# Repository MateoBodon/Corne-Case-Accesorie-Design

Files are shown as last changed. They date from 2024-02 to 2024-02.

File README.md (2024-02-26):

# Magnetic Cases for the Typeractive Corne


## Introduction

Welcome to the repository hosting my magnetic keyboard case designs for the Typeractive Corne keyboard. 

In this collection, you'll discover innovative solutions tailored to enhance your mechanical keyboard experience. Below is a list of the designs available, offered in both slim and thick variants:

- A magnetic keyboard case
- A magnetic carrying case
- A magnetic wrist rest

These designs are specifically made for the 5 column Choc keyboard, with plans to accommodate other sizes in the future.

### About the Typeractive Corne Keyboard

The parts to build the Typeractive Corne Keyboard can be purchased at [typeractive.xyz](https://typeractive.xyz). For resources and help building the keyboard, you can refer to their documentation [here](https://docs.typeractive.xyz/build-guides/corne-wireless) and this YouTube video [https://youtu.be/uT9ohua2RwY](https://youtu.be/uT9ohua2RwY). The magnetic cases are designed for completely assembled builds, ensuring a perfect fit and seamless integration with your custom Typeractive Corne Keyboard.

## Features

### Keyboard Case
- **Cutouts for Power and Reset Switch:** Allows easy access to essential controls without removing the case.
- **Magnetic Attachment:** Utilizes 19 magnets for secure attachment to both the carrying case and wrist rest.
- **Rubber Feet Shaped Grooves:** Enhances installation ease and improves balance.
- 
- 

### Carrying Case
- **Symbol Indicators:** Features embedded left and right symbols for quick orientation.
- **Finger Shaped Cutouts:** Offers easy removal of the keyboard from the case.
- **USB-C Port Cutout:** Enables charging or the use of magnetic cables without removing the keyboard.
- **Magnetic Attachment:** Comes with 15 magnets for a strong link to the keyboard case.
- 
- 

### Wrist Rest
- **Contoured Shape:** Designed to perfectly fit the keyboard case for maximum comfort.
- **Ergonomic Curve:** Inspired by effective wrist rest designs for prolonged typing comfort.
- **Rubber Feet Shaped Grooves:** Similar to the keyboard case for stability and ease of installation.
- **Leather Sheet:** Adds a layer of comfort and enhances the aesthetic.
- **Magnetic Attachment:** Features 10 magnets for easy attachment to the keyboard case.
- 
- 

## Getting Started

This section will guide you through the process of choosing, downloading, and preparing the STL files for printing. We offer designs in both Slim and Thick variants to cater to different preferences and requirements.

### Materials List

#### Shared:

- **Magnets (88 required)**: Used to hold the keyboard case and carrying case together, and to hold the keyboard case and wrist rest together. It's crucial to get these exact magnets if possible, as magnet strength varies and the parts have been designed with these magnets in mind. If not available, make sure to use 6mm by 2mm round magnets and adjust the count as needed for strength. [Purchase here](https://www.amazon.com/gp/product/B07XRQ44VC/ref=ppx_yo_dt_b_search_asin_title?ie=UTF8&psc=1). I suggest purchasing more than the required amount as it is easy to mess up the alignment, requiring you to restart.

- **Rubber Feet (16 required)**: The keyboard case and wrist rest have indentations in the bottom meant for these rubber feet. [Purchase here](https://keeb.io/products/skuf-silicone-rubber-keyboard-feet).

 - **Super Glue**: Essential for securing the magnets in their designated slots. The recommended glue is Starbond EM-150 Medium, known for its strong hold. However, application can be tricky due to its flow; it's hard to control how much comes out, and excess glue tends to ooze out when not in use. [Purchase here](https://www.amazon.com/Starbond-EM-150-Medium-Premium-Cyanoacrylate/dp/B00C32MHJU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). Additional products under testing for ease of application and control include (Will update my recommendation after use):
    - **Loctite Super Glue**: Offers strong adhesion with better control over the flow, appearing to be a strong contender for ease of use. [Purchase here](https://www.amazon.com/dp/B0006HUJCQ?ref=ppx_yo2ov_dt_b_product_details&th=1).
    - **Bob Smith Glue/Activator Combo**: Also looks promising for both control and hold, potentially offering a more user-friendly application process. [Purchase here](https://www.amazon.com/dp/B0166FFCHS?ref=ppx_yo2ov_dt_b_product_details&th=1).

- **Disposable Gloves**: Recommended for when gluing magnets as it can get a bit messy. These can be found on Amazon, local stores, or other online retailers.

- **Parchment Paper**: Also recommended for the gluing process to prevent the glue from sticking to your work surface. Available at Amazon, local grocery stores, or craft stores.
- 
- **Leather Sheet**: If you choose to apply a leather sheet on your wrist rest for enhanced aesthetics and comfort. [Purchase here](https://www.amazon.com/gp/product/B08N68MVZD/ref=ppx_yo_dt_b_search_asin_title?ie=UTF8&psc=1).

- **Exacto Knife**: Essential for precision cutting of the wrist rest shapes out of the leather. [Purchase here](https://www.amazon.com/Fiskars-Exacto-Precision-Crafts-Protective/dp/B001A42CTW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).

#### Slim Variant Exclusive:

- **110mAh 301230 Battery (2 required)**: Ensure the size of your battery matches the 301230 dimensions (30mm x 12mm x 3mm). [Purchase here](https://typeractive.xyz/products/lithium-battery-110mah?variant=43294731665639).

- **Standoff and Screws**: You most likely won’t need these assuming you got your keyboard from Typeractive, as it already comes with the necessary screws and standoffs. [Purchase here if needed](https://www.amazon.com/gp/product/B07B9X1KY6/ref=ppx_yo_dt_b_search_asin_title?ie=UTF8&psc=1).

#### Thick Variant Exclusive:

- **Soldering Iron**: Required for the construction of the Thick Variant.

- **Heatset Inserts and Tools**: Due to the thickness of the case, heatset inserts are used to create a thread for the standoffs. [Purchase inserts here](https://www.amazon.com/gp/product/B09MTS6ZZQ/ref=ppx_yo_dt_b_search_asin_title?ie=UTF8&th=1). [Purchase tools here](https://www.amazon.com/gp/product/B09MTS6ZZQ/ref=ppx_yo_dt_b_search_asin_title?ie=UTF8&th=1).

- **Standoffs and Screws**: Used for attaching the board to the heatset inserts. [Purchase here](https://www.amazon.com/gp/product/B07B9X1KY6/ref=ppx_yo_dt_b_search_asin_title?ie=UTF8&psc=1).

- **1000mAh 523450 Battery (2 required)**: Ensure the size of your battery matches 523450 dimensions (52mm x 34mm x 5mm), and the battery lead should be about as long as the battery itself. [Purchase here](https://www.amazon.com/gp/product/B07BTHH72G/ref=ppx_yo_dt_b_search_asin_title?ie=UTF8&psc=1).

Now that you're familiar with the materials required for both variants, let's move on to choosing your variant and preparing for assembly.

### Choosing Your Variant

- **Slim Variants**: Designed for minimalism and portability, the Slim Variant utilizes a smaller 110mAh battery. The case thickness is 16mm, and the carrying case measures 17.25mm. Please note, the Slim Variant is incompatible with display covers (e.g., the Typeractive Corne Display Cover available at [typeractive.xyz/products/corne-display-cover](https://typeractive.xyz/products/corne-display-cover)) to maintain its sleek profile.
  
- **Thick Variants**: Built for extended use and durability, the Thick Variant incorporates a larger 1000mAh battery embedded within the case. It measures 21mm for the case and 25.25mm for the carrying case, offering more room for additional components.

### Battery Life Expectations

The battery life varies significantly between the Slim and Thick variants, especially when using a nice!view display:

- **Slim Variant Battery Life**:
  - Central Board: Approximately 1 week and 6 days (±3 days)
  - Peripheral: Approximately 2 months and 3 weeks (±3 weeks)

- **Thick Variant Battery Life**:
  - Central Board: Approximately 3 months and 1 week (±4 weeks)
  - Peripheral: Approximately 10 months and 3 weeks (±3 months)

For detailed insights into battery life calculations and optimizations, please refer to the [ZMK Power Profiler](https://zmk.dev/power-profiler).

### STL Files and Preparation

We have provided the STL files for all parts required to assemble the cases. Below you will find links to the Slim and Thick variants of the cases. Choose the variant that best suits your needs and follow the instructions provided within each folder.

- [Slim Variants](Choc-5col-Slim/)
- [Thick Variants](Choc-5col-Thick/)

### Comparison Image




By selecting the appropriate variant and preparing your parts according to the instructions, you'll be on your way to assembling a functional and stylish magnetic keyboard case. Happy building!

## Attributions

This project would not have been possible without the collaborative efforts of several key individuals in the keyboard community. Special thanks to:

- **Jonathan Hsu (Jyojoh)** - For his invaluable assistance with prototyping and design. Jonathan's own collection of case designs serves as a great resource for enthusiasts and can be found [here](https://github.com/jyojoh/case-designs/tree/main).

- **Nick Winans** - The founder of Nice-Keyboards and the creator of the Typeractive Corne. Learn more about his contributions [here](https://github.com/Nicell).

- **Kosuke Adachi** - The original creator of the Corne Keyboard. Kosuke's pioneering work laid the foundation for this project and many others within the community. His GitHub profile can be found [here](https://github.com/foostan).

## Contributing

We welcome contributions from the community. Whether you're looking to improve on the existing designs, have suggestions for new features, or want to share your own magnetic case designs, please feel free to reach out or submit a pull request.

## License

This project is licensed under the MIT License - see the [LICENSE](LICENSE) file for details.

The MIT License is a permissive license that is short and to the point. It lets people do anything they want with your project as long as they provide attribution back to you and don’t hold you liable.

## Contact

Should you have any questions or wish to connect with me for collaborations, please do not hesitate to get in touch.

- **Mateo Bodon** - [mateobodon@gmail.com](mailto:mateobodon@gmail.com)

Thank you for your interest in Magnetic Cases for the Typeractive Corne. I look forward to growing this project with your support and feedback.

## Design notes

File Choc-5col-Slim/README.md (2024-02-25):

# Slim Variant - Magnetic Cases for the Typeractive Corne

## Introduction

The slim variant of the magnetic cases for the Typeractive Corne is designed for minimalism and portability. The Slim Variant utilizes a smaller 110mAh battery. The case thickness is 16mm, and the carrying case measures 17.25mm. Please note, the Slim Variant is incompatible with display covers (e.g., the Typeractive Corne Display Cover available at typeractive.xyz/products/corne-display-cover) to maintain its sleek profile.

Learn more about the differences between the slim and thick variant [here](https://github.com/MateoBodon/Corne-Case-Accesorie-Design#choosing-your-variant).

See the part list for the Slim variant [here](https://github.com/MateoBodon/Corne-Case-Accesorie-Design#getting-started).

Included in this folder are STL files for the magnetic keyboard case, magnetic carrying case, and magnetic wrist rest.

## Instructions

1) Print all the needed parts either with your own printer or a printing service. 

    **Printing Instructions:**
    - No Supports are needed for any of the parts.
    - A .16 layer height is recommended for the keyboard case and carrying case (although any layer height should work).
    - An infill percentage between 30-50 percent is recommended for the keyboard case and carrying case, (any infill percentage should work however 30-50 makes the prints feel more sturdy, if you wish to make it sturdier print at an infill percentage higher than 50 at the cost of time and materials).
    - Make sure to orient the carrying case so that the flat side is facing down, the walls should be facing up.
    - When printing the wrist rest an infill percentage of 50% and higher is recommended, this is due to the incline of the wrist rest, lower infill percentages can lead to artifacting on the incline. A higher infill percentage also makes the wrist rest feel sturdier. (I personally print it at 80% infill).
    - When printing the wrist rest choose a smaller layer height of between .08 and .12 this is so that the incline is more natural and has less bumps. (I personally print it at .08 layer height) If your printing software allows for variable layer heights I recommend that option for the wrist rest (ex. Bambu lab).

2) Prepare a safe space to glue your magnets into their holes. You may want to use a piece of parchment paper to prevent glue from getting on your surface. I suggest wearing disposable gloves during the process.

3) Starting with the keyboard case and using a small tip for your super glue, insert a few drops into a hole and push the magnet inside, be careful not to have the other magnets nearby as they may push the magnet out of the hole, try and avoid getting glue on the plastic, if it does occur quick use a paper towel to dab it up. Allow each magnet to sit for about 20 seconds before moving onto the next one. Continue until all the magnets are inserted.  Tip: It is possible to use the other magnets on the outside of the keyboard case to move the magnet into the hole, insert one magnet in the keyboard case, and use a stack of magnets to guide it into the hole.

4) Now one by one place your magnets on the outside of the keyboard case, there are 19 magnets in the case so you should have 15 on the outside. Skip placing corresponding magnets to the 4 on the bottom middle of the keyboard case (the only side of the keyboard case with 4 magnets and are placed very close to each other), these are used exclusively for the wrist rest and will be used later. Each one of your 15 magnets should align with a magnet on the interior.

5) Now grab the corresponding sides carrying case (right and right or left and left) and position it in the same orientation as the keyboard case so that the magnet positions align. It is very important that it is aligned properly so you understand which corresponding magnet should go where. Now one by one grab magnets off of the keyboard case and place them into their corresponding hole on the carrying case (the outer side of the magnet facing away from the keyboard case when attached should be facing the interior of the carrying case magnet hole so that they are attracted to each other) It is very important to pay attention here and make sure you don't switch any of the magnet directions by accident. A failure in direction could mean having to go through the process again if it won't come out.

6) Allow all the magnets to set and make sure to complete both the left and right side. It is a very similar process for the wrist rest. Place 10 magnets on the bottom exterior of the keyboard case, making sure each one aligns with a magnet on the interior. Then position your wrist rest in the same orientation as the keyboard case making sure it aligns, and follow the same process of taking the magnets and gluing them into their corresponding holes on the wrist rest. The outer side of the magnet facing away from the keyboard case when attached should be facing the interior of the wrist rest magnet hole so that they are attracted to each other. It is very important to pay attention here and make sure you don't switch any of the magnet directions by accident. A failure in direction could mean having to go through the process again if it won't come out. Tip: Be careful when placing the 4 magnets that are close together on one side, due to their closeness, placing the 4 consecutively can lead to the magnets flying out as the glue is setting. To alleviate this, hold down the magnet while the glue is setting. Don't glue those 4 consecutively; take your time and allow each one to set before placing the next. Arranging the poles so that they are alternating also seems to help but is not necessary (i.e., 1st North facing out, 2nd South facing out, 3rd North Facing out, 4th South Facing out).

7) The hard part is over now that your magnets are all inserted. We can now install the keyboard. First, install the standoffs. There are 5 holes in the base of the keyboard case, insert an M2 screw in each one from the bottom and screw on the M2 standoff. Place the completed PCB (ensure the PCB is built completely) on top of the standoffs and screw the keyboard in with 5 M2 screws.

8) At this point, your keyboard is ready to go. Try out all the magnetic parts and make sure everything is working and looks good. Ensure you have sufficient magnetic strength between the keyboard case and carrying case. If there isn't enough strength, assuming you used the magnets recommended, you most likely have a magnet facing the wrong way. If you can't get it out of the hole, you may need to redo that specific part.

9) If you wish to install a leather sheet on top of your wrist rest, make your way over to the Flattened Wrist Rest Shape Print Out page [here](https://github.com/MateoBodon/Corne-Case-Accesorie-Design/tree/main/Flattened%20Wrist%20Rest%20Shape%20Printout) and print out both the right and left sheets. These sheets are a flattened version of the surface of the wrist rest. You will use these sheets to cut the shape out of the leather. Place one of the sheets on top of the leather and, with your Exacto Knife, cut out the shape of the wrist rest by tracing the edge on the page. Make sure to hold down the leather to avoid slipping and miscuts. After you are done, you should have a cutout roughly the size of the wrist rest. You can now stick it onto the wrist rest by taking off the adhesive page on the back (assuming you are using the leather sheet recommended; if not, you can glue it onto the wrist rest). If it is too small, try to center it on the wrist rest to avoid it looking off; if too long, center it on the wrist rest and trim off the edges.

10) Congrats on your new keyboard! Have fun!

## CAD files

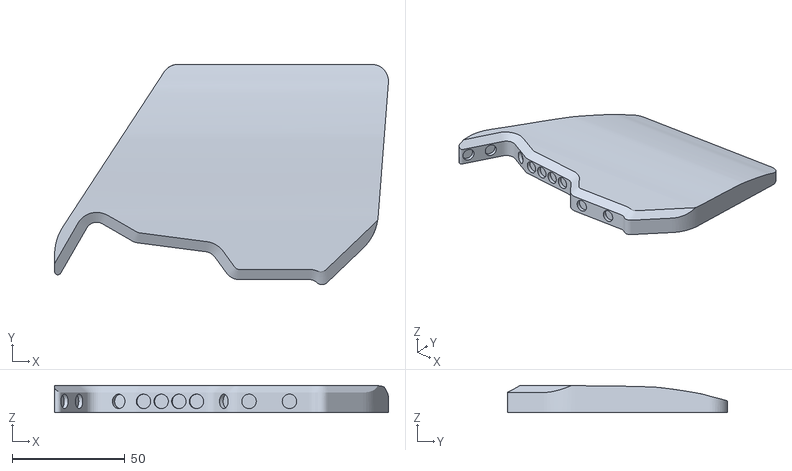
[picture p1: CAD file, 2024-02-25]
Choc-5col-Slim/Wrist Rest Left.stl
148.2 x 97.7 x 12.1

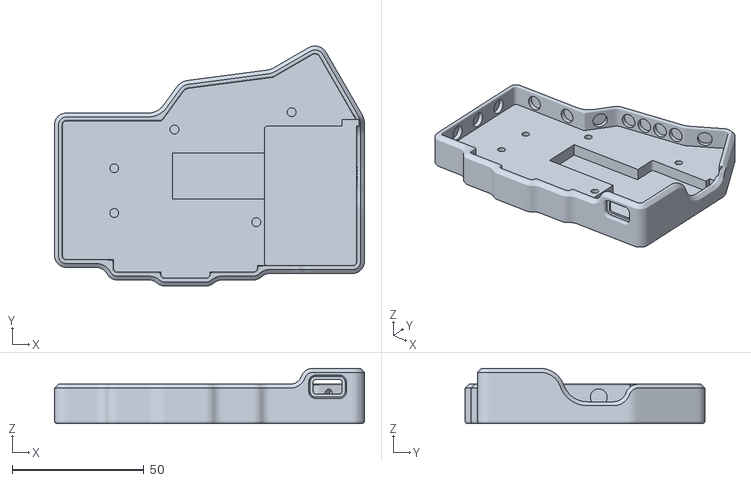
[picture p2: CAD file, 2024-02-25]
Choc-5col-Thick/Keyboard Case Right.stl
117.8 x 91.2 x 21.0

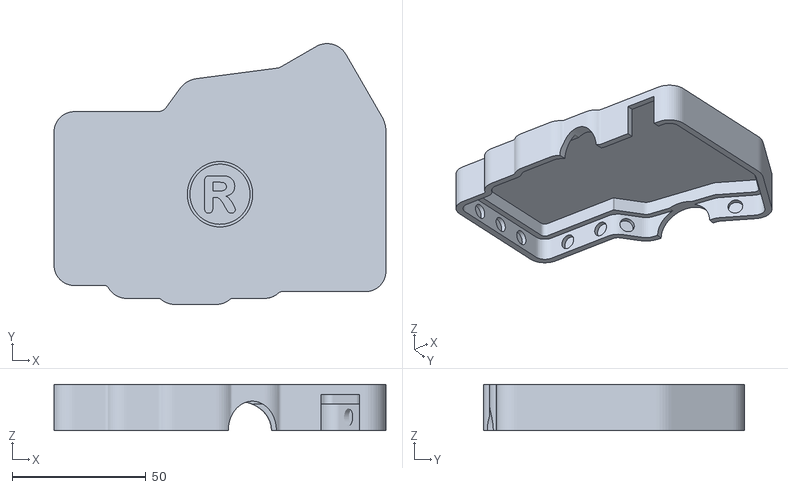
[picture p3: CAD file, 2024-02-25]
Choc-5col-Slim/Carrying Case Right.stl
124.2 x 97.6 x 17.2

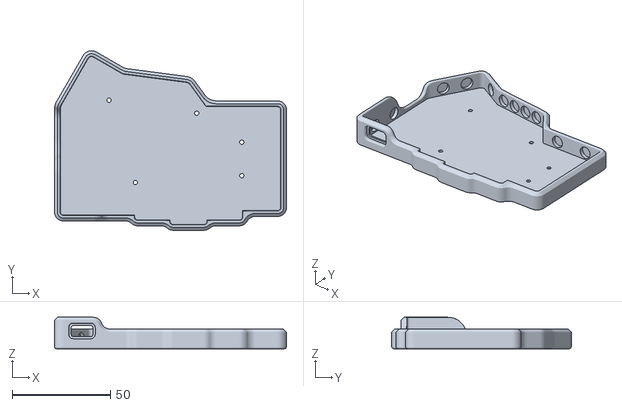
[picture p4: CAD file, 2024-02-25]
Choc-5col-Slim/Keyboard Case Left.stl
117.8 x 91.2 x 16.0

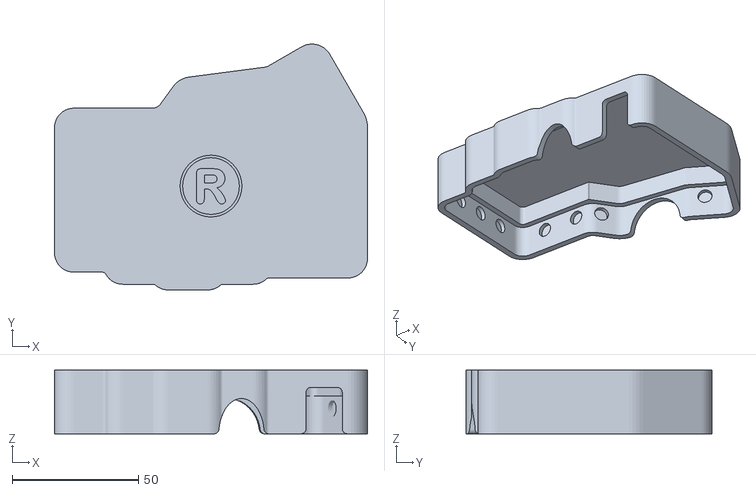
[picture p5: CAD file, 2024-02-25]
Choc-5col-Thick/Carrying Case Right.stl
124.2 x 97.6 x 25.2

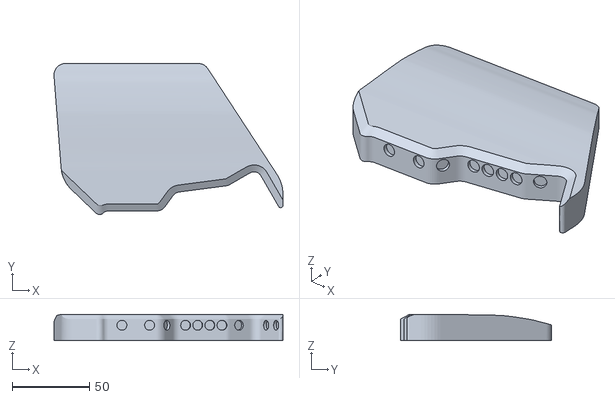
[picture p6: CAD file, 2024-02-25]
Choc-5col-Thick/Wrist Rest Right.stl
148.2 x 97.7 x 17.1

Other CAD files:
Choc-5col-Thick/Keyboard Case Left.stl
Choc-5col-Slim/Carrying Case Left.stl
Choc-5col-Slim/Wrist Rest Right.stl
Choc-5col-Thick/Wrist Rest Left.stl
Choc-5col-Slim/Keyboard Case Right.stl
Choc-5col-Thick/Carrying Case Left.stl

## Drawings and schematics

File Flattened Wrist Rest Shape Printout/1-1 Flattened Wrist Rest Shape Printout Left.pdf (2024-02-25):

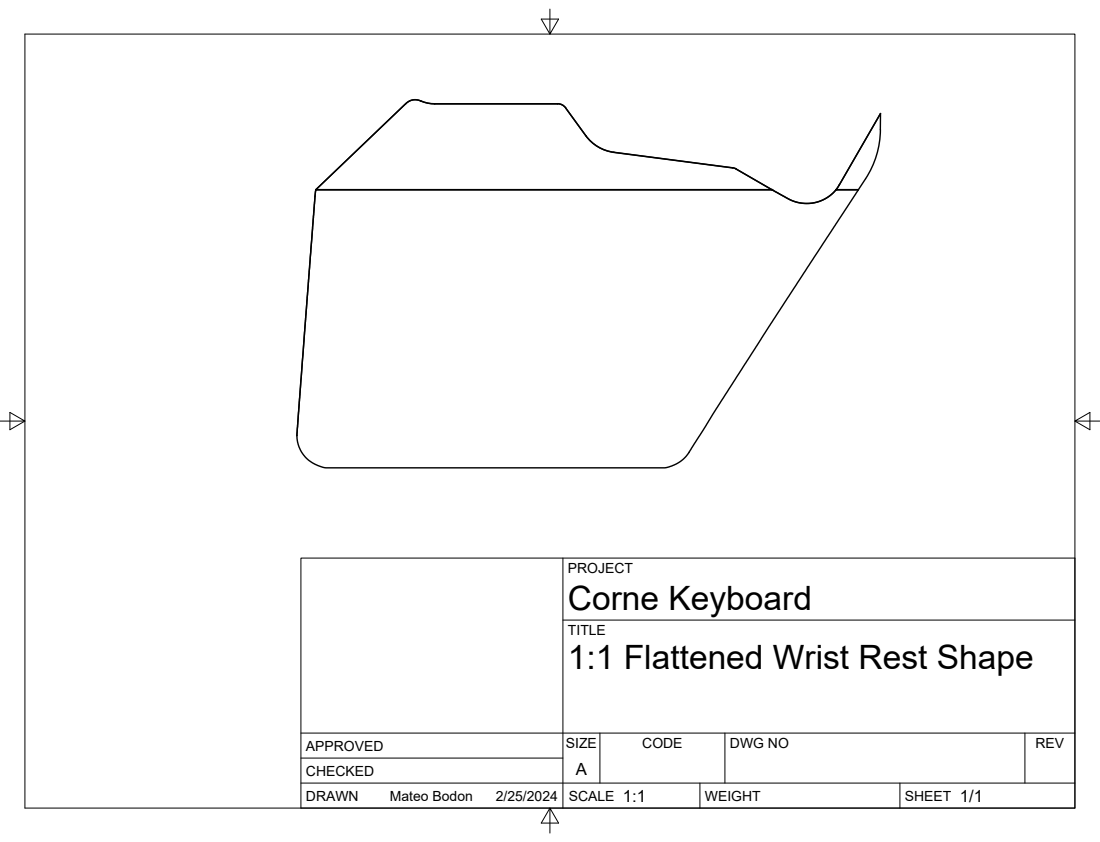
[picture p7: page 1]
SIZE; CODE; DWG NO; REV; Mateo Bodon

PROJECT
Corne Keyboard
1:1 Flattened Wrist Rest Shape

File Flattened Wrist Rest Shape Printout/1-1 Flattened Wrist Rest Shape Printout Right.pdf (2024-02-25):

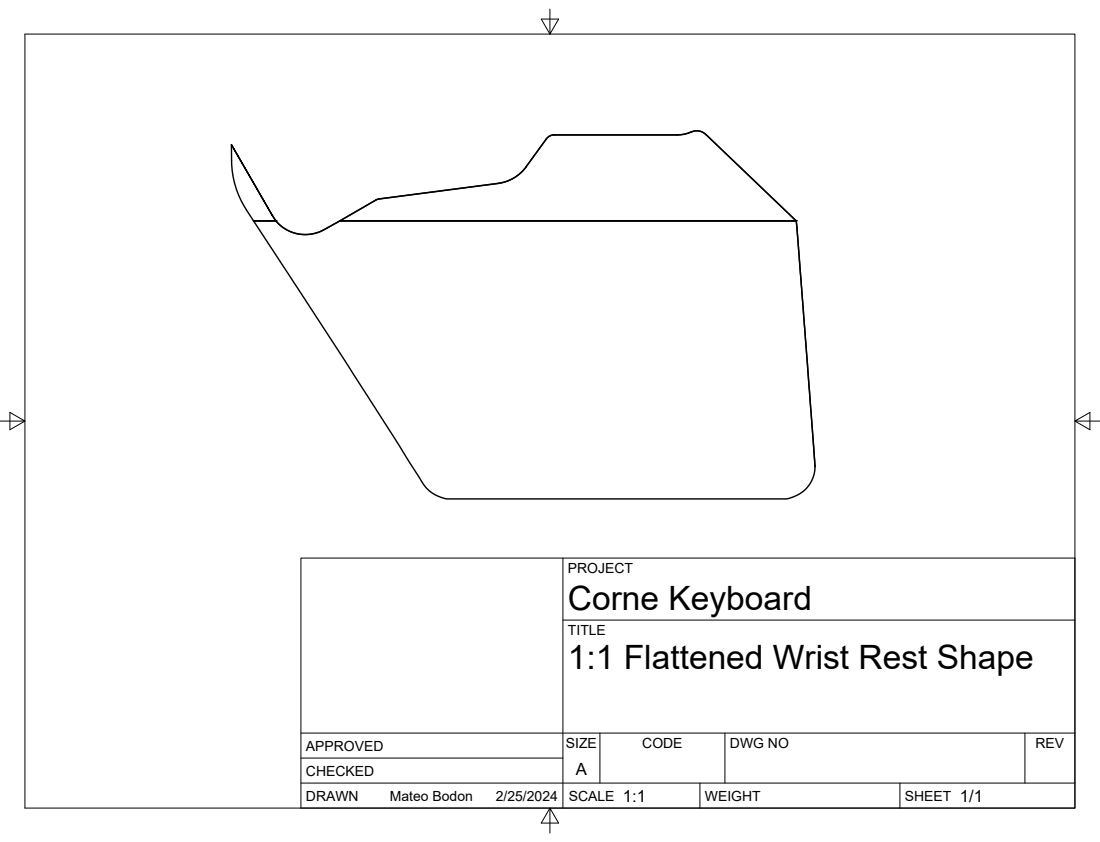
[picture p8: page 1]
SIZE; CODE; DWG NO; REV; Mateo Bodon

PROJECT
Corne Keyboard
1:1 Flattened Wrist Rest Shape

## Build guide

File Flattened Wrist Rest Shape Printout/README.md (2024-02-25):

# Wrist Rest Printouts for Typeractive Corne Magnetic Cases

## Introduction

This folder contains 1:1 scale flattened versions of the curved surface on the wrist rest for the Typeractive Corne keyboard cases. These printouts are designed to be used as guides for cutting materials such as leather to fit the wrist rest perfectly.

## Usage

1. Print out the templates included in this folder. Ensure your printer settings are set to print at actual size or 100% scale to maintain the 1:1 ratio.

2. Place the printed template over your chosen leather or material.

3. Carefully use an Exacto Knife to cut around the template, creating a piece that will fit onto the wrist rest of your keyboard case.

## Instructions

For detailed instructions on how to apply the cutout to your wrist rest, please refer to the assembly instructions in the corresponding variant folder:

- [Slim Variants](Choc-5col-Slim/)
- [Thick Variants](Choc-5col-Thick/)

Please handle all tools with care and follow safety procedures when cutting materials to avoid injury.

Happy crafting and enjoy your customized keyboard wrist rest!

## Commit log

2024-02-25 Added STL Files
    [Carrying Case Left.stl, Carrying Case Right.stl, Keyboard Case Left.stl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]
2024-02-25 Added Flattened Printouts for Wrist Rest
    These are used to cutout leather to place on top of the wrist rests
